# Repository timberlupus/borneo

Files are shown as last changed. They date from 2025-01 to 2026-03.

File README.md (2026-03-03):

# BorneoIoT: Professional Aquarium Lighting Platform








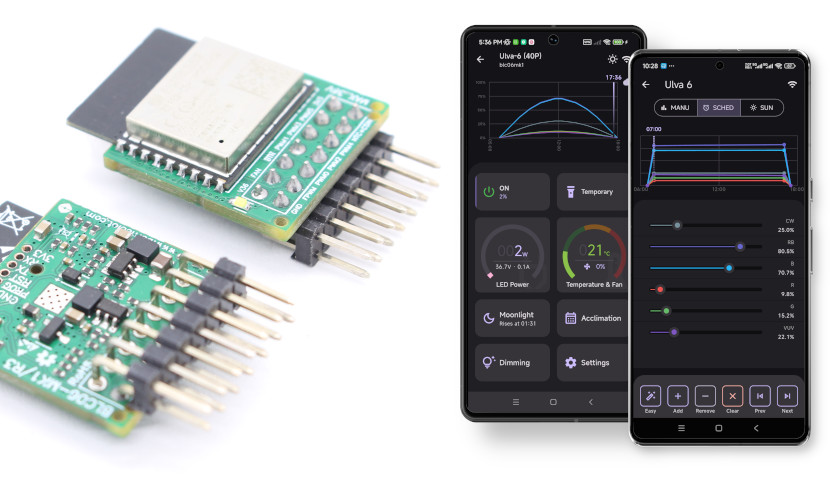
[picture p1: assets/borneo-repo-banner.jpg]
BorneoIoT Banner


<p align="center">
        <a href="https://www.borneoiot.com"><b>Website</b></a> •
        <a href="https://docs.borneoiot.com"><b>Documentation</b></a> •
        <a href="https://github.com/borneo-iot/borneo/discussions"><b>Forum</b></a> •
        <a href="https://discord.gg/EFJTm7PpEs"><b>Discord</b></a> •
</p>

<p align="center">
    <a href="https://www.crowdsupply.com/borneo-iot/buce-aquarium-led-controller" target="_blank" rel="noopener">
        
    </a>
    <a href="https://flasher.borneoiot.com">
        
    </a>

</p>

> **Production-grade open-source stack for aquarium LED dimmers.**
> Hardware designs, embedded firmware, and mobile controls. Ready for weekend builds or product integration.

This project delivers a full-stack solution for smart aquarium LED:

1.  **Hardware**: Certified open-source PCB designs targeting the ESP32 family, featuring 6-channel PWM dimming and modular architecture.
2.  **Firmware**: A robust ESP-IDF based firmware implementing CoAP/CBOR protocols, sunrise/sunset simulation, and cooling control.
3.  **Mobile App**: A cross-platform Flutter application for intuitive real-time control, scheduling, and device management.

## Quick Start

**New users:** Follow the **[step-by-step guide](https://docs.borneoiot.com/getting-started/quick-start.html)** to flash firmware and connect your first device.

**No toolchain required**, flash directly from Chrome/Edge Browser:

1. Connect ESP32/ESP32-C3/ESP32-C5 via USB
2. Visit **[flasher.borneoiot.com](https://flasher.borneoiot.com)**
3. Download the app and power on

[Full Getting Started Guide](https://docs.borneoiot.com/getting-started)

## Features

### Hardware

- **6 or 10 PWM channels**, 12-bit resolution (4096 steps), up to 19kHz
- **Flicker-free**, suitable for aquarium photography
- **22×30mm core module**, fits slim LED fixtures
- ESP32-C3/C5 native, WiFi + Bluetooth LE

[Schematics & BoM](hw/)

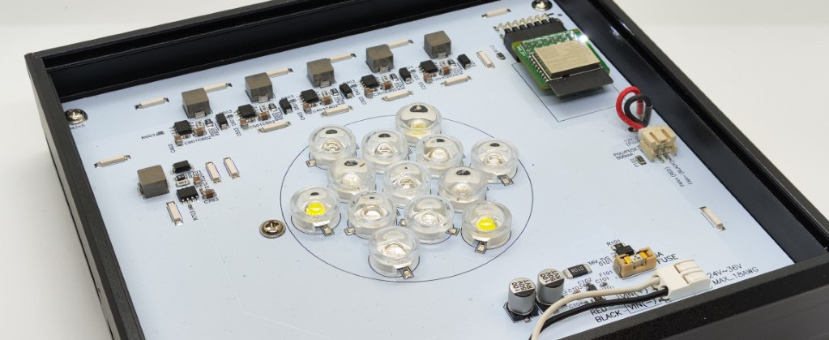
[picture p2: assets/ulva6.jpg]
Ulva-6


### Firmware

- **Sunrise/sunset curves** with millisecond-smooth transitions
- **SNTP time sync**: automatic, no manual adjustment
- **Active cooling control**: temperature-based fan/PWM throttling
- **OTA updates**: over-the-air firmware upgrades
- **CoAP + CBOR protocol**: efficient, low-latency device communication

[Source code](fw/) • [Protocol docs](https://docs.borneoiot.com/protocol)

### Mobile App

- **Cross-platform**: iOS, Android, Windows, built with Flutter
- **Real-time control**: dimming, scheduling, scene presets
- **Multi-device**: group control, cloud-free local network
- **Developer API**: Python client for automation

[App source](client/) • [Python SDK](borneopy/)

## Repository Guide

| Directory | Contents | Entry Point |
|---|---|---|
| [`hw/`](hw/) | PCB designs (Horizon EDA), Gerbers, 3D models | [`hw/README.md`](hw/) |
| [`fw/`](fw/) | ESP-IDF firmware, CoAP protocol | [`fw/README.md`](fw/) |
| [`client/`](client/) | Flutter mobile app | [`client/README.md`](client/) |
| [`borneopy/`](borneopy/) | Python client library | [`borneopy/README.md`](borneopy/) |

## Getting Started

- **New Users**: Check out our [**Quick Start Guide**](https://docs.borneoiot.com/getting-started/quick-start.html).
- If you are a new user looking to quickly experience our firmware, you can directly use our web firmware flasher to flash the latest version of the firmware to your ESP32 series development board: https://flasher.borneoiot.com/
- **Hardware**: Find schematics and BoM files in the [`hw/`](hw/) directory.
- **Firmware**: Compilation instructions are available in the [`fw/`](fw/) folder.

## Project Status

| Component | Status | Details |
| :--- | :--- | :--- |
| **Hardware** | Stable | Production-ready, OSHWA certified. |
| **Firmware** | Beta | Full-featured and stable on my personal tanks for years. |
| **Mobile App** | Beta | Core functionality working. |

## Roadmap

Check our [milestones](https://github.com/borneo-iot/borneo/milestones) for the latest development updates and upcoming features.

## Community & Support

- **Website**: [www.borneoiot.com](https://www.borneoiot.com)
- **Documentation**: [docs.borneoiot.com](https://docs.borneoiot.com)
- **Discussions**: [Join the Conversation](https://github.com/borneo-iot/borneo/discussions)
- **Discord**: [Connect with Developers](https://discord.gg/EFJTm7PpEs)
- **Email**: [info@binarystarstech.com](mailto:info@binarystarstech.com)

## Licenses

- **Software/Firmware**: Dual-licensed under [**GPL-3.0+**](LICENSE) and Enterprise licenses.
- **Hardware**: Licensed under [**CERN-OHL-S-2.0**](LICENSE-HARDWARE).

---

The hardware, firmware, and App for this project were all created by: Wei Li（李维）.

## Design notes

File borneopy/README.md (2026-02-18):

# borneo.py

A open-source Python client library for devices under the Borneo-IoT Project.

## Features

- Basic device control (power on/off, reboot, factory reset, etc.)
- Device information queries
- Timezone settings
- Firmware upgrade checking
- CoAP OTA firmware updates

## Installation

```bash
pip install -r requirements.txt
```

## Usage Examples

### Basic Device Control

```python
import asyncio
from borneo.lyfi import LyfiCoapClient

async def main():
    async with LyfiCoapClient("coap://192.168.1.100") as device:
        # Get device information
        info = await device.get_info()
        print(f"Device info: {info}")
        
        # Control device power
        await device.set_on_off(True)
        status = await device.get_on_off()
        print(f"Device status: {status}")

if __name__ == "__main__":
    asyncio.run(main())
```

### CoAP OTA Firmware Update

```python
import asyncio
from borneo.lyfi import LyfiCoapClient

async def update_firmware():
    device_url = "coap://192.168.1.100"
    firmware_path = "firmware.bin"
    
    def progress_callback(current, total):
        percent = int((current / total) * 100)
        print(f"Upload progress: {percent}%")
    
    def status_callback(message):
        print(f"Status: {message}")
    
    async with LyfiCoapClient(device_url) as device:
        # Check OTA status
        status = await device.check_ota_status()
        if status['success']:
            print(f"Current partition: {status['current_partition']}")
        
        # Execute OTA update
        result = await device.perform_ota_update(
            firmware_path,
            progress_callback=progress_callback,
            status_callback=status_callback
        )
        
        if result['success']:
            print("Firmware update successful!")
        else:
            print(f"Update failed: {result['error']}")

if __name__ == "__main__":
    asyncio.run(update_firmware())
```

## Command Line Tools

### `bocli` — command-line tool 🔧

`bocli` is the console script provided by this package (see `pyproject.toml`).
Install the package to get the `bocli` command (`pip install -e .`) or run via `uv run bocli`.

Usage:

```text
bocli [global options] <command> [command options]
```

Global options
- `-h, --host`  Device base URL for CoAP commands (e.g. `coap://192.168.1.10`)
- `-v, --verbose`  Increase verbosity (repeatable)
- `-c, --compatible`  Compatibility string (default: `bst,borneo-lyfi`)
- `--version`  Print version and exit

Available commands
- `lota` — perform local OTA over CoAP
  - usage: `bocli -h coap://192.168.1.100 lota firmware.bin [--block-size 512] [--status-only]`
  - note: `fw_path` is required; `--status-only` will only query OTA status and exit
- `mdns` — discover devices via mDNS (e.g. `bocli mdns -t 5` or `bocli mdns --find`)
- `get` — call `get_<what>` on `LyfiCoapClient` and print JSON
  - usage: `bocli -h coap://192.168.1.100 get color`
  - list targets: `bocli -h coap://192.168.1.100 get --list`
- `capabilities` — list available `get_...` methods (supports `--json`)
- `on` / `off` — turn device on / off (e.g. `bocli -h coap://192.168.1.100 on`)
- `factory-reset` — perform factory reset (use `-y` to bypass confirmation)

Examples
```bash
# discover devices with mDNS for 3 seconds
bocli mdns -t 3

# list `get_...` targets supported by the device
bocli -h coap://192.168.1.100 get --list

# get a resource (prints JSON)
bocli -h coap://192.168.1.100 get color

# turn device on
bocli -h coap://192.168.1.100 on

# perform OTA (upload firmware)
bocli -h coap://192.168.1.100 lota firmware.bin
# check OTA status only (fw_path is still required by the CLI)
bocli -h coap://192.168.1.100 lota firmware.bin --status-only
```

See `borneo/cli.py` for full command descriptions and options.

## API Documentation

### CoAP OTA Methods

#### `check_ota_status()`
Check device OTA status.

**Returns:**
```python
{
    'success': bool,
    'current_partition': str,      # Current running partition
    'update_status': str,          # Update status
    'bytes_received': int          # Bytes received
}
```

#### `upload_firmware(firmware_path, progress_callback=None)`
Upload firmware file to device.

**Parameters:**
- `firmware_path`: Path to firmware file
- `progress_callback`: Optional progress callback function `callback(current, total)`

**Returns:**
```python
{
    'success': bool,
    'message': str,
    'next_boot': str,              # Next boot partition
    'checksum': str,               # File checksum
    'size': int                    # File size
}
```

#### `perform_ota_update(firmware_path, progress_callback=None, status_callback=None)`
Execute complete OTA update process.

**Parameters:**
- `firmware_path`: Path to firmware file
- `progress_callback`: Optional progress callback function `callback(current, total)`
- `status_callback`: Optional status callback function `callback(message)`

**Returns:**
```python
{
    'success': bool,
    'message': str,
    'details': dict                # Detailed result information
}
```

## Dependencies

- `aiocoap>=0.4.12` - CoAP protocol support
- `cbor2>=5.6.5` - CBOR data format support
- `aiofiles` - Async file operations

## Packaging & development

This project uses a modern PEP 621 `pyproject.toml` (setuptools backend). Below are common development and packaging commands.

- Build distributions:
  - `python -m build` (uses build backend from `pyproject.toml`)
  - `uv build` (if you use Astral's `uv` tool)

- Create and activate a local virtual environment (Windows):
  - `python -m venv .venv`
  - `.venv/Scripts/activate`

- Install dependencies for development:
  - `pip install -e .`
  - or `uv pip sync` / `uv venv` when using `uv`

- Run an example:
  - `python examples/hello_lyfi.py`

- Publish to PyPI:
  - `uv publish`
  - or `python -m twine upload dist/*`

Notes:
- **License:** `GPL-3.0-or-later` — please add or verify a `LICENSE` file in the repository.
- The project was migrated from `setup.py` to `pyproject.toml`; builds produce both `sdist` and `wheel` artifacts.

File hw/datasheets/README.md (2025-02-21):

# Datasheets

This folder contains the schematics and datasheets for the hardware developed in this project.

| Module / Name | Datasheet | Other Language Version |
|:--- | :--- | :--- |
| Buce (BLC06MK1) Module Datasheet | [`blc06mk1.pdf`](blc06mk1.pdf) | - |
| Buce (BLC06MK1) Module Schematic | [`blc06mk1r4_sch.pdf`](blc06mk1r4_sch.pdf) | - |

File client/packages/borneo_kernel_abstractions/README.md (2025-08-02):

# Borneo Kernel Abstractions

This package provides core abstractions and interfaces for the Borneo project kernel.

## Features

- Device and driver interfaces
- Device event bus
- Command queue
- Error types for device operations
- mDNS discovery abstractions
- Bound device and driver data models

## Usage

Add to your `pubspec.yaml` dependencies:

```yaml
dependencies:
  borneo_kernel_abstractions:
    path: packages/borneo_kernel_abstractions
```

Import what you need:

```dart
import 'package:borneo_kernel_abstractions/kernel.dart';
```

Or import specific interfaces or models:

```dart
import 'package:borneo_kernel_abstractions/ikernel.dart';
```

## License

See [LICENSE](LICENSE).

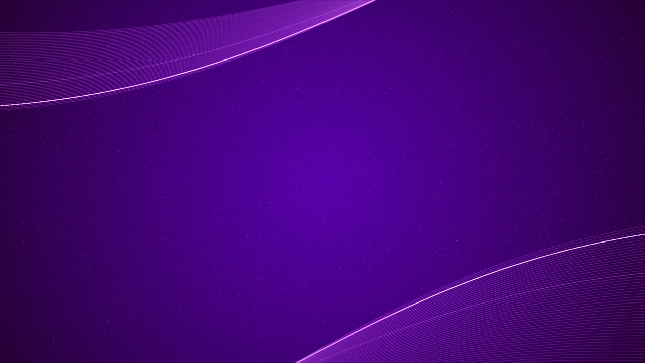
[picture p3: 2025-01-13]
client/assets/images/scenes/scene-default-noimage.jpg

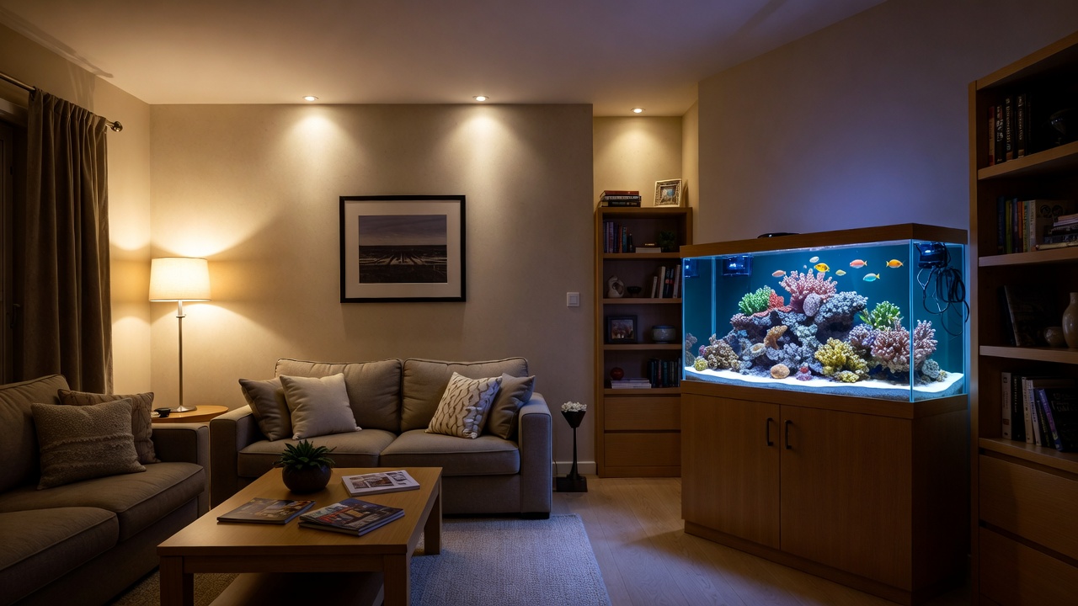
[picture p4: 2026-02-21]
client/assets/images/scenes/scene-default-home.jpg

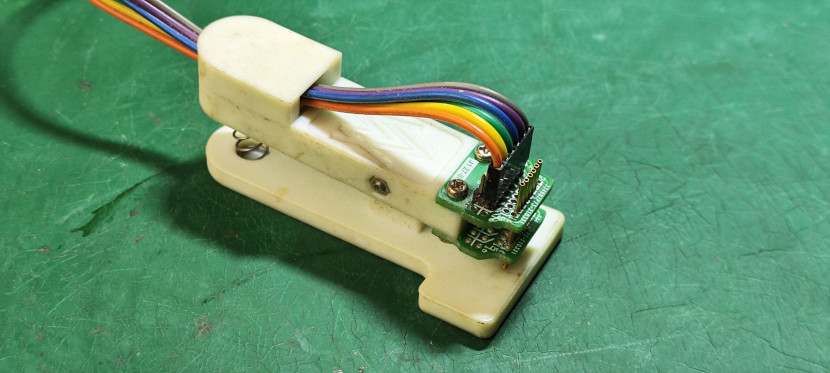
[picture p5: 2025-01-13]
assets/programming-clamp.jpg

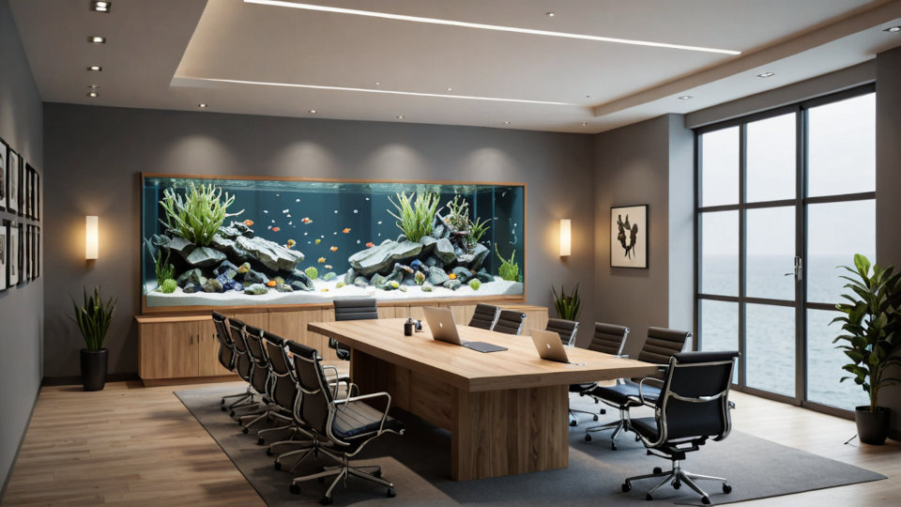
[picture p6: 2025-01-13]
client/assets/images/scenes/scene-default-office.jpg

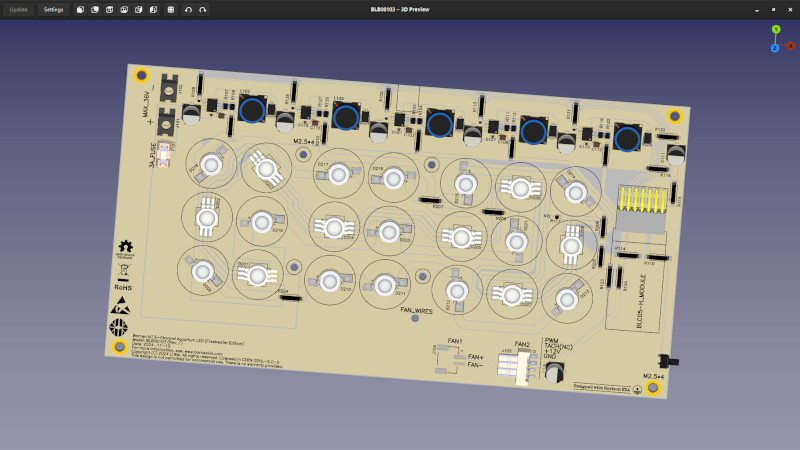
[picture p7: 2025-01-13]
assets/blb08103.jpg

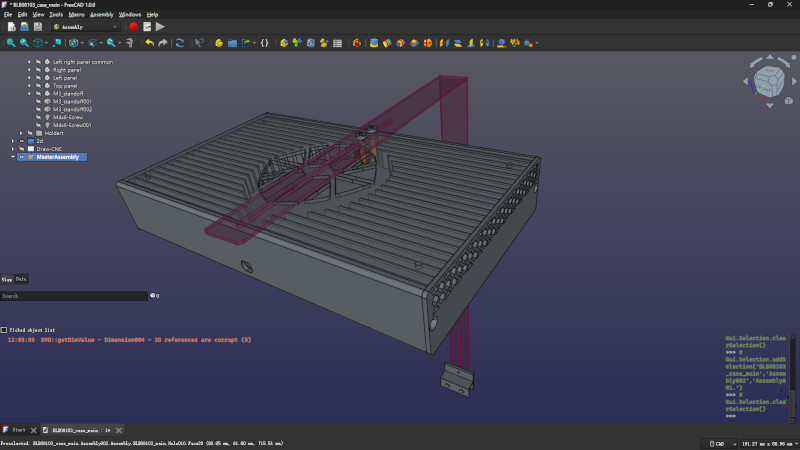
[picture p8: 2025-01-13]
assets/blb08103-case.jpg

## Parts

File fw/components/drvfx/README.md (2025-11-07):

# DRVFX: ESP-IDF modular device driver framework

## Overview

Borrowed from Zephyr RTOS: an ESP-IDF modular device driver framework.

## Purpose

This component provides a small, modular driver/kernel abstraction for device drivers used by the project. It centralizes device registration, initialization, and driver interfaces so platform drivers can be developed and reused consistently.

## Layout

- `include/drvfx/`: public headers for the framework and drivers.
- `drivers/`: example and platform drivers (RTC driver located under `drivers/rtc`).
- `kernel/`: core implementation (kernel/device/init source files).
- `LICENSE.txt`: licensing for this component.

Key headers are under `include/drvfx/kernel` and `include/drvfx/drivers` and provide the API surface for integrating drivers.

## Usage

Add the component to your ESP-IDF project as usual (CMake/IDF component). Include the public headers from `include/drvfx` and use the provided kernel/device APIs to register and manage drivers. Consult the `drivers/` directory for usage examples.

### Subsystem init

Use `DRVFX_SUBSYS_INIT` to register a subsystem initialization function that runs at the POST_KERNEL stage. The init function signature is:

```c
int init_fn(const struct drvfx_device *dev);
```

For subsystem entries `dev` will be NULL. Return 0 on success; non-zero indicates failure. Priority controls ordering (use constants like `DRVFX_INIT_POST_KERNEL_DEFAULT_PRIORITY`).

Example:

```c
/* module.c */
#include <drvfx/kernel/init.h>

static int my_subsys_init(const struct drvfx_device *dev)
{
    (void)dev; /* subsys entries have no device */
    /* perform subsystem setup here */
    return 0;
}

/* Register the subsystem init at post-kernel default priority */
DRVFX_SUBSYS_INIT(my_subsys_init, DRVFX_INIT_POST_KERNEL_DEFAULT_PRIORITY);
```

Notes:

- Use `DRVFX_SYS_INIT` / `DRVFX_SYS_INIT_NAMED` when you need a system init entry associated with the init function name.
- Subsystem inits run automatically during kernel initialization (e.g., when `k_init()` is invoked). After init, use `k_device_get_binding()` and `k_device_is_ready()` to access devices.

## Driver development example — foo

This example shows a minimal driver API for a device type `foo` whose API exposes a single function `foo_read(dev, buf, size)`.

Header (`foo.h`):

```c
#pragma once

#include <errno.h>
#include <drvfx/drvfx.h>

#ifdef __cplusplus
extern "C" {
#endif

struct foo_api {
    int (*read)(const struct drvfx_device *dev, void *buf, size_t size);
};

/* User-land API: forwards the call to the driver implementation. */
static inline int foo_read(const struct drvfx_device *dev, void *buf, size_t size)
{
    const struct foo_api *api = (const struct foo_api *)dev->api;
    return api->read(dev, buf, size);
}

#ifdef __cplusplus
}
#endif
```

Driver implementation (`foo.c`):

```c
#include <drvfx/drvfx.h>

static int foo_read_impl(const struct drvfx_device *dev, void *buf, size_t size)
{
    (void)dev;
    /* perform read into buf up to size bytes */
    return 0; /* return number of bytes read or negative on error */
}

static int foo_init(const struct drvfx_device *dev)
{
    (void)dev;
    /* hardware init for foo */
    return 0;
}

static const struct foo_api foo_api_impl = {
    .read = foo_read_impl,
};

/* Define a static device and attach the API pointer */
DRVFX_DEVICE_DEFINE(
    "foo0",
    foo_init,
    NULL,
    NULL, DRVFX_INIT_POST_KERNEL_DEFAULT_PRIORITY,
    &foo_api_impl
);
```

Runtime usage:

```c
#include <drvfx/drvfx.h>
#include "your_drivers_dir/foo.h"

void drvfx_app_main(void)
{
    const struct drvfx_device *dev = k_device_get_binding("foo0");
    if (dev && k_device_is_ready(dev)) {
        const struct foo_api *api = (const struct foo_api *)dev->api;
        if (api && api->read) {
            char buf[32];
            int rc = api->read(dev, buf, sizeof(buf));
            // ...
        }
    }
}
```

Notes:

- Place the API definition in a public header, like under `include/your_porj/drivers/` so consumers can include it.
- Provide driver-specific `init` that sets up hardware and returns `0` on success.
- Attach the API pointer as the last argument to `DRVFX_DEVICE_DEFINE` so callers can cast `dev->api` to the driver API.

## Contributing / Contact

Follow the repository contribution guidelines. Open an issue or pull request in the main repository for feedback or improvements.

## License

This component is licensed in Apache 2.0 License.
See `LICENSE.txt` in this component for licensing details.

Copyright (C) 2024-TODAY Yunnan BinaryStars Technologies, Co., Ltd. All rights reserved.

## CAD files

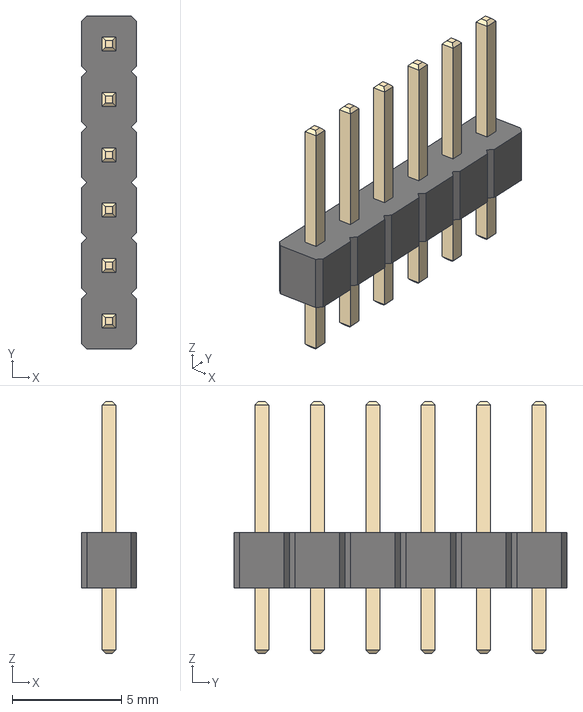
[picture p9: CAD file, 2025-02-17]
hw/bdb6mk1/pool/3d_models/cache/6d752bc3-29b3-45df-8cf2-1e3aacefbcc6/3d_models/connector/header/2.54mm/PinHeader_1x06_P2.54mm_Vertical.step
2.54 x 15.2 x 11.5 mm

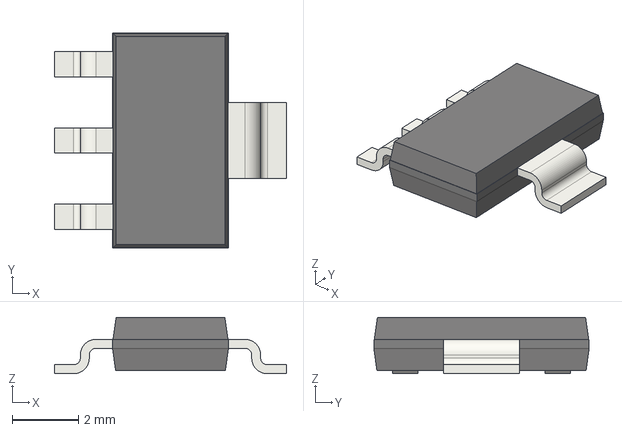
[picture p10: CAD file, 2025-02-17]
hw/bdb6mk1/pool/3d_models/cache/6d752bc3-29b3-45df-8cf2-1e3aacefbcc6/3d_models/ic/so/SOT-223.step
7.00 x 6.50 x 1.70 mm

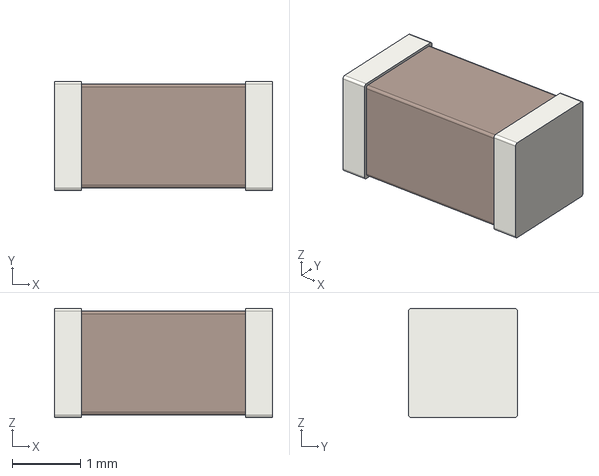
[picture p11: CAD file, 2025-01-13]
hw/bdb6mk1/pool/3d_models/cache/6d752bc3-29b3-45df-8cf2-1e3aacefbcc6/3d_models/passive/capacitor/C_1206_3216Metric.step
3.20 x 1.60 x 1.60 mm

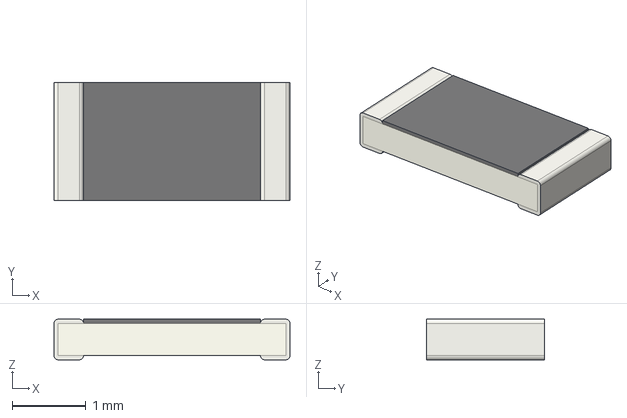
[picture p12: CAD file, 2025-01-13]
hw/bdb6mk1/pool/3d_models/cache/6d752bc3-29b3-45df-8cf2-1e3aacefbcc6/3d_models/passive/resistor/R_1206_3216Metric.step
3.20 x 1.60 x 0.55 mm

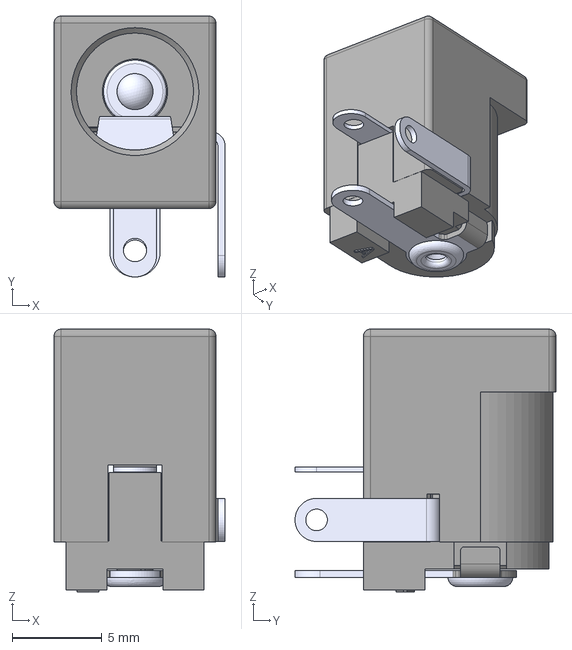
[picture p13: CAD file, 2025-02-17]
hw/bdb6mk1/pool/3d_models/cache/8eeaf956-e4a0-4db5-95bb-b90e600e8069/3d_models/connector/barrel-jack/DC-001-A-2.1mm-R.STEP
9.50 x 14.5 x 14.6 mm

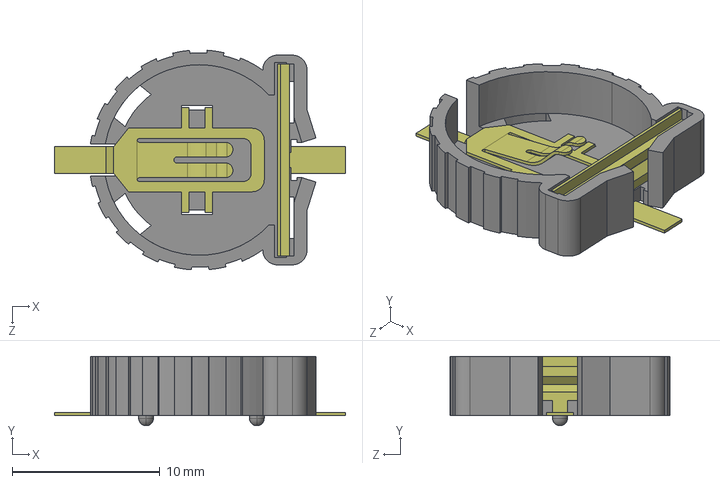
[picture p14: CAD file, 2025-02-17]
hw/bdb6mk1/pool/3d_models/cache/8eeaf956-e4a0-4db5-95bb-b90e600e8069/3d_models/connector/battery-holder/CR1220-2.stp
19.7 x 4.70 x 14.9 mm

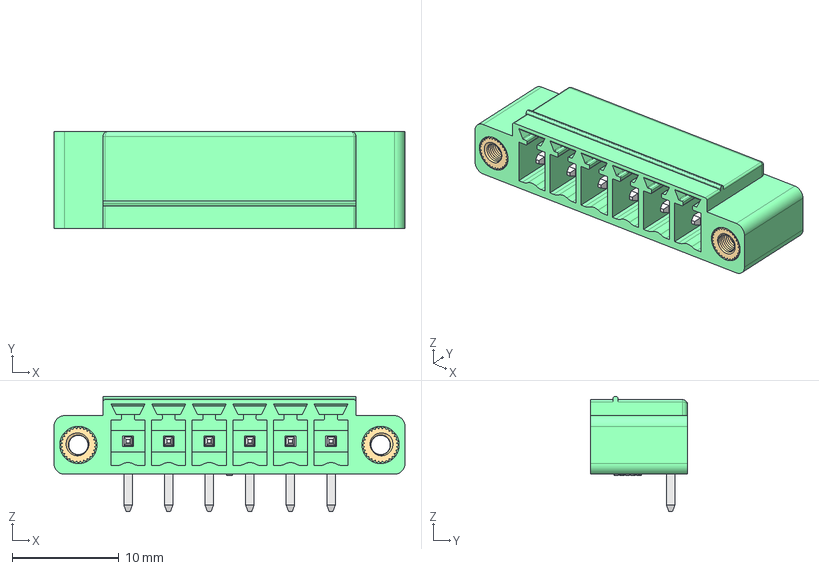
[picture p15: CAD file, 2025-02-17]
hw/bdb6mk1/pool/3d_models/cache/8eeaf956-e4a0-4db5-95bb-b90e600e8069/3d_models/connector/terminal-block/kangnex/WJ15EDGRM-3.81-06P.step
32.9 x 9.15 x 10.8 mm

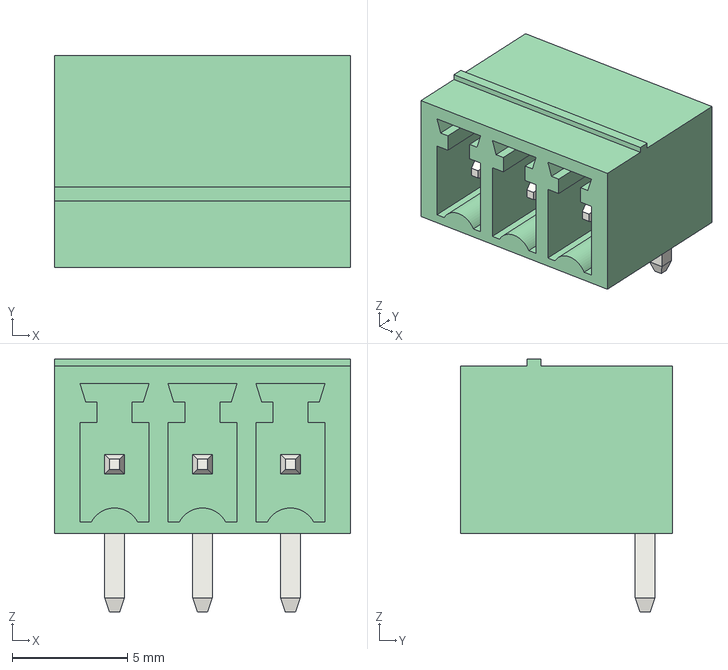
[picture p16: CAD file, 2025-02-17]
hw/bdb6mk1/pool/3d_models/cache/8eeaf956-e4a0-4db5-95bb-b90e600e8069/3d_models/connector/terminal-block/phoenix-contact-mc/PhoenixContact_MC_1,5_3-G-3.81_1x03_P3.81mm_Horizontal.step
12.8 x 9.20 x 10.9 mm

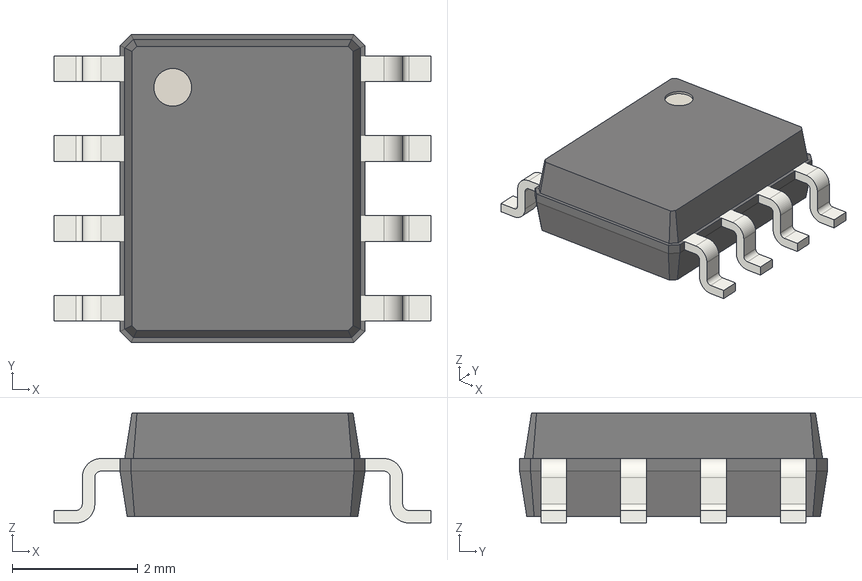
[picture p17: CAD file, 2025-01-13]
hw/bdb6mk1/pool/3d_models/cache/8eeaf956-e4a0-4db5-95bb-b90e600e8069/3d_models/ic/so/SOIC-8_3.9x4.9mm_P1.27mm.step
6.00 x 4.90 x 1.75 mm

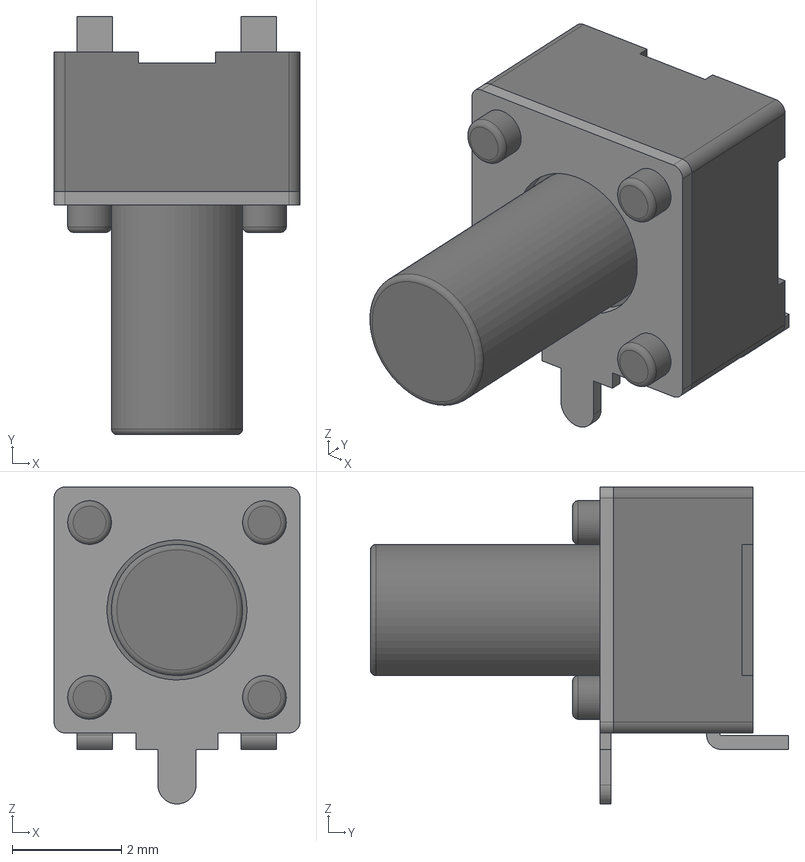
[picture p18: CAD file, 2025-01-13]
hw/bdb6mk1/pool/3d_models/cache/8eeaf956-e4a0-4db5-95bb-b90e600e8069/3d_models/mechanical/switch/krhro/K2-1109SE-I4SW-04.step
4.50 x 7.65 x 5.80 mm
Main
FrontPlate
Pin1
Pin2

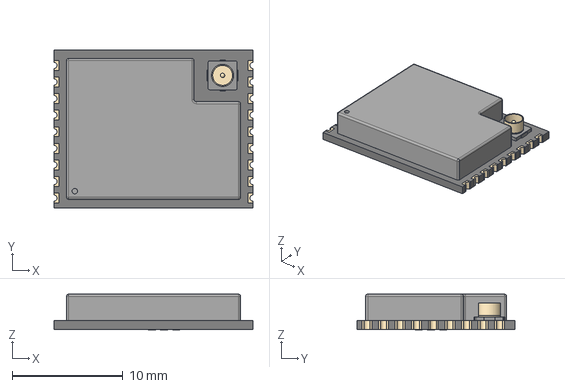
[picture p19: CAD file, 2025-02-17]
hw/bdb6mk1/pool/3d_models/cache/8eeaf956-e4a0-4db5-95bb-b90e600e8069/3d_models/module/rf/espressif/ESP32-C3-WROOM-02U.step
18.0 x 14.3 x 3.24 mm

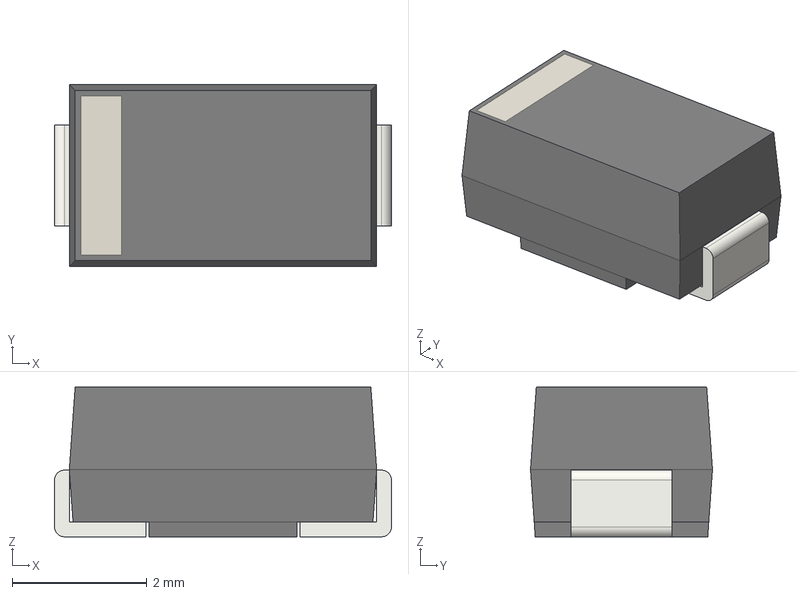
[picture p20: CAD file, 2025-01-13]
hw/blb0657f/pool/3d_models/cache/6d752bc3-29b3-45df-8cf2-1e3aacefbcc6/3d_models/diode/D_SMA.step
5.00 x 2.70 x 2.22 mm

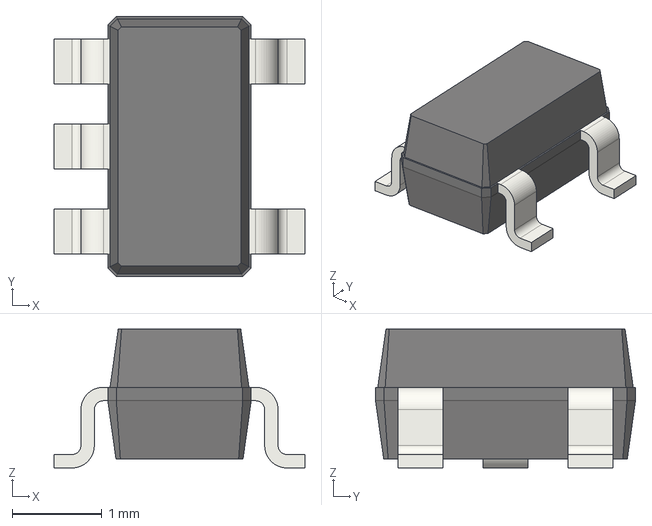
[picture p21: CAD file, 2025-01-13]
hw/blb0657f/pool/3d_models/cache/6d752bc3-29b3-45df-8cf2-1e3aacefbcc6/3d_models/ic/so/SOT-23-5.step
2.80 x 2.90 x 1.55 mm

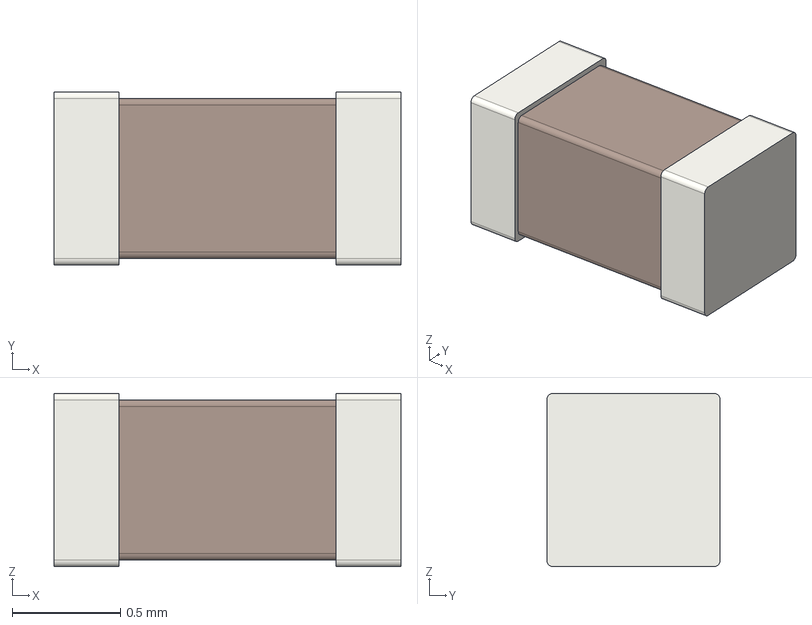
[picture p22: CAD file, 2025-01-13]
hw/blb0657f/pool/3d_models/cache/6d752bc3-29b3-45df-8cf2-1e3aacefbcc6/3d_models/passive/capacitor/C_0603_1608Metric.step
1.60 x 0.8 x 0.8 mm

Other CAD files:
hw/blb0657f/pool/3d_models/cache/6d752bc3-29b3-45df-8cf2-1e3aacefbcc6/3d_models/passive/resistor/R_0805_2012Metric.step
hw/blb0657f/pool/3d_models/cache/8eeaf956-e4a0-4db5-95bb-b90e600e8069/3d_models/connector/b2w/2.54mm/2510_4p_smd_horizontal.step
hw/blb0657f/pool/3d_models/cache/8eeaf956-e4a0-4db5-95bb-b90e600e8069/3d_models/connector/b2w/jst/2.00mm/S2B-PH-SM4-TB_LF__SN_.step
hw/blb0657f/pool/3d_models/cache/8eeaf956-e4a0-4db5-95bb-b90e600e8069/3d_models/connector/header/2.54mm/PinHeader_2x07_P2.54mm_Horizontal.step
hw/bdb6mk1/pool/3d_models/cache/6d752bc3-29b3-45df-8cf2-1e3aacefbcc6/3d_models/ic/so/SOT-23.step
hw/bdb6mk1/pool/3d_models/cache/8eeaf956-e4a0-4db5-95bb-b90e600e8069/3d_models/module/rf/espressif/ESP32-C3-WROOM-02.STEP
hw/blb0657f/pool/3d_models/cache/8eeaf956-e4a0-4db5-95bb-b90e600e8069/3d_models/connector/b2w/jst/2.00mm/S4B-PH-SM4-TB_LF__SN_.step
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

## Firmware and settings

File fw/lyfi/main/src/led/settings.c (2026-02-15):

#include <string.h>
#include <time.h>
#include <errno.h>
#include <math.h>
#include <stdio.h>
#include <ctype.h>

#include <esp_system.h>
#include <esp_event.h>
#include <esp_timer.h>
#include <freertos/FreeRTOS.h>
#include <freertos/task.h>
#include <freertos/semphr.h>
#include <driver/ledc.h>
#include <esp_err.h>
#include <esp_log.h>
#include <nvs_flash.h>
#include <esp_rom_md5.h>

#include <borneo/common.h>
#include <borneo/system.h>
#include <borneo/power.h>
#include <borneo/nvs.h>

#include "../lyfi-events.h"
#include "led.h"

#define LED_NVS_NS "led"
#define LED_NVS_KEY_RUNNING_MODE "mode"
#define LED_NVS_KEY_MANUAL_COLOR "mcolor"
#define LED_NVS_KEY_SUN_COLOR "suncolor"
#define LED_NVS_KEY_MOON_COLOR "mooncolor"
#define LED_NVS_KEY_SCHEDULER "sch"
#define LED_NVS_KEY_TEMPORARY_DURATION "tmpdur"
#define LED_NVS_KEY_CORRECTION_METHOD "corrmtd"
#define LED_NVS_KEY_PWM_FREQ "pwmfreq"
#define LED_NVS_KEY_CHANNEL_COUNT "chcount"
#define LED_NVS_KEY_LOC "loc"
#define LED_NVS_KEY_TZ_ENABLED "tz_en"
#define LED_NVS_KEY_TZ_OFFSET "tz_off"
#define LED_NVS_KEY_ACCLIMATION_ENABLED "acc.en"
#define LED_NVS_KEY_ACCLIMATION_START "acc.start"
#define LED_NVS_KEY_ACCLIMATION_DURATION "acc.days"
#define LED_NVS_KEY_ACCLIMATION_START_PERCENT "acc.pc"
#define LED_NVS_KEY_CLOUD_ENABLED "cloud.en"
#define LED_NVS_KEY_MOON_ENABLED "moon.en"

#define TAG "led.settings"

static const struct led_user_settings LED_DEFAULT_SETTINGS = {
    .mode = LED_MODE_MANUAL,
    .temporary_duration = 20,
    .manual_color = {
// From kconfig
#if CONFIG_LYFI_LED_CH0_ENABLED
        205,
#endif
#if CONFIG_LYFI_LED_CH1_ENABLED
        205,
#endif
#if CONFIG_LYFI_LED_CH2_ENABLED
        205,
#endif
#if CONFIG_LYFI_LED_CH3_ENABLED
        205,
#endif
#if CONFIG_LYFI_LED_CH4_ENABLED
        205,
#endif
#if CONFIG_LYFI_LED_CH5_ENABLED
        205,
#endif
#if CONFIG_LYFI_LED_CH6_ENABLED
        205,
#endif
#if CONFIG_LYFI_LED_CH7_ENABLED
        205,
#endif
#if CONFIG_LYFI_LED_CH8_ENABLED
        205,
#endif
#if CONFIG_LYFI_LED_CH9_ENABLED
        205,
#endif
    },

    .correction_method = LED_CORRECTION_CIE1931,

    .sun_color = { 0 },
    .moon_color = { 0 },
    .scheduler = { 0 },

    .location = { // Kunming, China
        .lat = 25.0430f,
        .lng = 102.7062f,
    },
    .tz_offset = 8 * 3600, // UTC+8

    .flags = 0ULL,

    .acclimation = {
        .start_utc = 0,
        .duration = 30,
        .start_percent = 30,
    },
};

struct led_channel_defaults {
    const char* name;
    const char* color;
    int16_t wavelength;
};

static const struct led_channel_defaults LED_DEFAULT_CHANNELS[CONFIG_LYFI_LED_CHANNEL_COUNT] = {
#if CONFIG_LYFI_LED_CH0_ENABLED
    [0] = {
            .name = CONFIG_LYFI_LED_CH0_NAME,
            .color = CONFIG_LYFI_LED_CH0_COLOR,
            .wavelength = CONFIG_LYFI_LED_CH0_WAVELENGTH,
        },
#endif
#if CONFIG_LYFI_LED_CH1_ENABLED
    [1] = {
            .name = CONFIG_LYFI_LED_CH1_NAME,
            .color = CONFIG_LYFI_LED_CH1_COLOR,
            .wavelength = CONFIG_LYFI_LED_CH1_WAVELENGTH,
        },
#endif
#if CONFIG_LYFI_LED_CH2_ENABLED
    [2] = { 
            .name = CONFIG_LYFI_LED_CH2_NAME,
            .color = CONFIG_LYFI_LED_CH2_COLOR,
            .wavelength = CONFIG_LYFI_LED_CH2_WAVELENGTH,
         },
#endif
#if CONFIG_LYFI_LED_CH3_ENABLED
    [3] = {
            .name = CONFIG_LYFI_LED_CH3_NAME,
            .color = CONFIG_LYFI_LED_CH3_COLOR,
            .wavelength = CONFIG_LYFI_LED_CH3_WAVELENGTH,
        },
#endif
#if CONFIG_LYFI_LED_CH4_ENABLED
    [4] = {
            .name = CONFIG_LYFI_LED_CH4_NAME,
            .color = CONFIG_LYFI_LED_CH4_COLOR,
            .wavelength = CONFIG_LYFI_LED_CH4_WAVELENGTH,
        },
#endif
#if CONFIG_LYFI_LED_CH5_ENABLED
    [5] = {
            .name = CONFIG_LYFI_LED_CH5_NAME,
            .color = CONFIG_LYFI_LED_CH5_COLOR,
            .wavelength = CONFIG_LYFI_LED_CH5_WAVELENGTH,
        },
#endif
#if CONFIG_LYFI_LED_CH6_ENABLED
    [6] = {
            .name = CONFIG_LYFI_LED_CH6_NAME,
            .color = CONFIG_LYFI_LED_CH6_COLOR,
            .wavelength = CONFIG_LYFI_LED_CH6_WAVELENGTH,
        },
#endif
#if CONFIG_LYFI_LED_CH7_ENABLED
    [7] = {
            .name = CONFIG_LYFI_LED_CH7_NAME,
            .color = CONFIG_LYFI_LED_CH7_COLOR,
            .wavelength = CONFIG_LYFI_LED_CH7_WAVELENGTH,
        },
#endif
#if CONFIG_LYFI_LED_CH8_ENABLED
    [8] = {
            .name = CONFIG_LYFI_LED_CH8_NAME,
            .color = CONFIG_LYFI_LED_CH8_COLOR,
            .wavelength = CONFIG_LYFI_LED_CH8_WAVELENGTH,
        },
#endif
#if CONFIG_LYFI_LED_CH9_ENABLED
    [9] = {
        .name = CONFIG_LYFI_LED_CH9_NAME,
        .color = CONFIG_LYFI_LED_CH9_COLOR,
        .wavelength = CONFIG_LYFI_LED_CH9_WAVELENGTH,
    },
#endif
};

static struct led_factory_settings s_factory_settings;
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

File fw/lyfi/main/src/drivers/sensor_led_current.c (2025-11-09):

#include <errno.h>
#include <nvs_flash.h>

#include "sdkconfig.h"

#include <freertos/FreeRTOS.h>
#include <freertos/event_groups.h>
#include <freertos/task.h>

#include <esp_timer.h>
#include <esp_attr.h>
#include <esp_event.h>
#include <esp_log.h>
#include <esp_sntp.h>
#include <esp_system.h>
#include <driver/gpio.h>
#include <esp_adc/adc_oneshot.h>

#include <drvfx/drvfx.h>

#include <borneo/algo/filters.h>
#include <borneo/common.h>
#include <borneo/system.h>
#include <borneo/devices/adc.h>
#include <borneo/devices/sensor.h>

#define TAG "sensor.led_current"

#define BO_ADC_WINDOW_SIZE 5

#if CONFIG_LYFI_MEAS_CURRENT_SUPPORT

#define LED_NVS_NS "led"
#define LED_NVS_KEY_MEAS_CURRENT_ENABLED "curr.en"

#ifndef CONFIG_LYFI_MEAS_CURRENT_OFFSET
#define CONFIG_LYFI_MEAS_CURRENT_OFFSET 0
#endif

struct sensor_current_data {
    const struct drvfx_device* adc_dev;
    int32_t current_ma;
    int32_t filtered_current;
};

struct power_meas_factory_settings {
    bool measurement_enabled;
};

/*
static struct power_meas_factory_settings s_factory_settings = {
    .measurement_enabled = true,
};
*/

/*
static int factory_settings_load(void)
{
    nvs_handle_t nvs_handle;
    BO_TRY(bo_nvs_factory_open(LED_NVS_NS, NVS_READWRITE, &nvs_handle));
    BO_NVS_AUTO_CLOSE(nvs_handle);

    bool changed = false;
    uint8_t enabled = 1;

    BO_TRY(bo_nvs_get_or_set_u8(nvs_handle, LED_NVS_KEY_MEAS_CURRENT_ENABLED, &enabled, 1, &changed));

    if (changed) {
        BO_TRY(nvs_commit(nvs_handle));
    }

    s_factory_settings.measurement_enabled = (enabled != 0);

    return 0;
}
*/

static int _fetch_sample(const struct drvfx_device* dev)
{
    if (dev == NULL) {
        return -ENODEV;
    }
    if (dev->data == NULL) {
        return -ENOSYS;
    }
    struct sensor_current_data* data = (struct sensor_current_data*)dev->data;

    int32_t adc_mv;
    BO_TRY(adc_read_mv(data->adc_dev, CONFIG_LYFI_MEAS_CURRENT_ADC_CHANNEL, &adc_mv));
    adc_mv -= CONFIG_LYFI_MEAS_CURRENT_OFFSET;
    if (adc_mv < 0) {
        adc_mv = 0;
    }
    int32_t raw_ma = (adc_mv * 1000 + (CONFIG_LYFI_MEAS_CURRENT_FACTOR / 2)) / CONFIG_LYFI_MEAS_CURRENT_FACTOR;
    data->current_ma = ema_filter(raw_ma, &data->filtered_current, 1, 10);
    return 0;
}

static int _get_value(const struct drvfx_device* dev, int32_t* value)
{
    if (dev == NULL) {
        return -ENODEV;
    }
    if (dev->data == NULL) {
        return -ENOSYS;
    }
    struct sensor_current_data* data = (struct sensor_current_data*)dev->data;
    *value = data->current_ma;
    return 0;
}

static int sensor_current_init(const struct drvfx_device* dev)
{
    if (dev == NULL) {
        return -ENODEV;
    }
    ESP_LOGI(TAG, "Initializing current sensor '%s'...", dev->name);

    if (dev->data == NULL) {
        return -ENOSYS;
    }
    struct sensor_current_data* data = (struct sensor_current_data*)dev->data;

    data->adc_dev = k_device_get_binding("adc");
    if (data->adc_dev == NULL) {
        ESP_LOGE(TAG, "Failed to get device 'adc'");
    }

    BO_TRY(_fetch_sample(dev));

    return 0;
}

const static struct sensor_api s_api = {
    .fetch_sample = &_fetch_sample,
    .get_value = &_get_value,
};

static struct sensor_current_data s_data = { 0 };

DRVFX_DEVICE_DEFINE("sensor.led_current", sensor_current_init, &s_data, NULL, DRVFX_INIT_POST_KERNEL_DEFAULT_PRIORITY,
                    &s_api);

#endif // CONFIG_LYFI_MEAS_CURRENT_SUPPORT

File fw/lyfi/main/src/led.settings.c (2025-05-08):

#include <string.h>
#include <time.h>
#include <errno.h>
#include <math.h>

#include <esp_system.h>
#include <esp_event.h>
#include <esp_timer.h>
#include <freertos/FreeRTOS.h>
#include <freertos/task.h>
#include <driver/ledc.h>
#include <esp_err.h>
#include <esp_log.h>
#include <nvs_flash.h>
#include <esp_rom_md5.h>

#include <borneo/common.h>
#include <borneo/system.h>
#include <borneo/power.h>
#include <borneo/nvs.h>

#include "lyfi-events.h"
#include "algo.h"
#include "led.h"

#define LED_NVS_NS "led"
#define LED_NVS_KEY_RUNNING_MODE "mode"
#define LED_NVS_KEY_MANUAL_COLOR "mcolor"
#define LED_NVS_KEY_SUN_COLOR "suncolor"
#define LED_NVS_KEY_SCHEDULER "sch"
#define LED_NVS_KEY_TEMPORARY_DURATION "tmpdur"
#define LED_NVS_KEY_CORRECTION_METHOD "corrmtd"
#define LED_NVS_KEY_PWM_FREQ "pwmfreq"
#define LED_NVS_KEY_LOC "loc"
#define LED_NVS_KEY_ACCLIMATION_ENABLED "acc.en"
#define LED_NVS_KEY_ACCLIMATION_START "acc.start"
#define LED_NVS_KEY_ACCLIMATION_DURATION "acc.days"
#define LED_NVS_KEY_ACCLIMATION_START_PERCENT "acc.pc"

static const struct led_user_settings LED_DEFAULT_SETTINGS = {
    .mode = LED_MODE_MANUAL,
    .temporary_duration = 20,
    .manual_color = {
// From kconfig
#if CONFIG_LYFI_LED_CH0_ENABLED
        5,
#endif
#if CONFIG_LYFI_LED_CH1_ENABLED
        5,
#endif
#if CONFIG_LYFI_LED_CH2_ENABLED
        5,
#endif
#if CONFIG_LYFI_LED_CH3_ENABLED
        5,
#endif
#if CONFIG_LYFI_LED_CH4_ENABLED
        5,
#endif
#if CONFIG_LYFI_LED_CH5_ENABLED
        5,
#endif
#if CONFIG_LYFI_LED_CH6_ENABLED
        5,
#endif
#if CONFIG_LYFI_LED_CH7_ENABLED
        5,
#endif
#if CONFIG_LYFI_LED_CH8_ENABLED
        5,
#endif
#if CONFIG_LYFI_LED_CH9_ENABLED
        5,
#endif
    },

    .correction_method = LED_CORRECTION_EXP,

    .sun_color = {0},
    .scheduler = { 0 },

    .location = {
        .lat = 25.0430f,
        .lng = 102.7062f,
    },

    .flags = 0ULL,

    .acclimation = {
        .enabled = false,
        .start_utc = 0,
        .duration = 30,
        .start_percent = 30,
    },
};

extern struct led_status _led;

int led_load_factory_settings(struct led_factory_settings* factory_settings)
{
    int rc;
    nvs_handle_t handle;
    rc = bo_nvs_factory_open(LED_NVS_NS, NVS_READWRITE, &handle);
    if (rc) {
        goto _EXIT_WITHOUT_CLOSE;
    }

    rc = nvs_get_u16(handle, LED_NVS_KEY_PWM_FREQ, &factory_settings->pwm_freq);
    if (rc == ESP_ERR_NVS_NOT_FOUND) {
        factory_settings->pwm_freq = CONFIG_LYFI_DEFAULT_PWM_FREQ;
        rc = 0;
    }
    if (rc) {
        goto _EXIT_CLOSE;
    }

_EXIT_CLOSE:
    bo_nvs_close(handle);
_EXIT_WITHOUT_CLOSE:
    return rc;
}

int led_load_user_settings()
{
    struct led_user_settings* settings = &_led.settings;
    int rc;
    size_t size;
    nvs_handle_t handle;
    rc = bo_nvs_user_open(LED_NVS_NS, NVS_READWRITE, &handle);
    if (rc) {
        goto _EXIT_WITHOUT_CLOSE;
    }

    {
        rc = nvs_get_u8(handle, LED_NVS_KEY_RUNNING_MODE, &settings->mode);
        if (rc == ESP_ERR_NVS_NOT_FOUND) {
            settings->mode = LED_DEFAULT_SETTINGS.mode;
            rc = 0;
        }
        if (rc) {
            goto _EXIT_CLOSE;
        }
    }

    {
        rc = nvs_get_u16(handle, LED_NVS_KEY_TEMPORARY_DURATION, &settings->temporary_duration);
        if (rc == ESP_ERR_NVS_NOT_FOUND) {
            settings->temporary_duration = LED_DEFAULT_SETTINGS.temporary_duration;
            rc = 0;
        }
        if (rc) {
            goto _EXIT_CLOSE;
        }
    }

    {
        size = sizeof(struct led_scheduler);
        rc = nvs_get_blob(handle, LED_NVS_KEY_SCHEDULER, &settings->scheduler, &size);
        if (rc == ESP_ERR_NVS_NOT_FOUND) {
            memcpy(&settings->scheduler, &LED_DEFAULT_SETTINGS.scheduler, sizeof(struct led_scheduler));
            rc = 0;
        }
        if (rc) {
            goto _EXIT_CLOSE;
        }
    }

    {
        size = sizeof(led_color_t);
        rc = nvs_get_blob(handle, LED_NVS_KEY_MANUAL_COLOR, &settings->manual_color, &size);
        if (rc == ESP_ERR_NVS_NOT_FOUND) {
            memcpy(&settings->manual_color, &LED_DEFAULT_SETTINGS.manual_color, sizeof(led_color_t));
            rc = 0;
        }
        if (rc) {
            goto _EXIT_CLOSE;
        }
    }

    {
        size = sizeof(led_color_t);
        rc = nvs_get_blob(handle, LED_NVS_KEY_SUN_COLOR, &settings->sun_color, &size);
        if (rc == ESP_ERR_NVS_NOT_FOUND) {
            memset(settings->sun_color, 0, sizeof(led_color_t));
            rc = 0;
        }
        if (rc) {
            goto _EXIT_CLOSE;
        }
    }

    {
        rc = nvs_get_u8(handle, LED_NVS_KEY_CORRECTION_METHOD, &settings->correction_method);
        if (rc == ESP_ERR_NVS_NOT_FOUND) {
            settings->correction_method = LED_DEFAULT_SETTINGS.correction_method;
            rc = 0;
        }
        if (rc) {
            goto _EXIT_CLOSE;
        }
    }
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

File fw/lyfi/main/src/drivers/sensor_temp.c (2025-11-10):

#include <string.h>
#include <sys/time.h>

#include <freertos/FreeRTOS.h>
#include <freertos/event_groups.h>
#include <freertos/task.h>

#include <esp_timer.h>
#include <esp_attr.h>
#include <esp_event.h>
#include <esp_log.h>
#include <esp_sntp.h>
#include <esp_system.h>
#include <driver/gpio.h>

#include <drvfx/drvfx.h>

#include <borneo/system.h>
#include <borneo/algo/filters.h>
#include <borneo/devices/adc.h>
#include <borneo/devices/sensor.h>

#if CONFIG_LYFI_NTC_SUPPORT

#define TAG "NTC"

struct ntc_data {
    const struct drvfx_device* adc_dev;
    int8_t temp_value;
    int32_t filtered_temp;
};

static int8_t ntc_table_lookup(int r);

#define NTC_SAMPLING_TIMES 8
#define NTC_TEMP_BUF_SIZE 16
#define NTC_ADC_MAX_VALUE 1023
#define ADC_WINDOW_SIZE 5

enum {
    NTC_SAMPLING_INTERVAL = 100,
    NTC_BAD_TEMPERATURE = -127,
};

// clang-format off

// 0~105 ℃

#if CONFIG_LYFI_NTC_PU_4K7
    // VRef=2.5V, 4.7kΩ Pull-up
const uint16_t NTC_MAPPING_TABLE[] = {
    2193, 2179, 2164, 2149, 2133, 2116, 2100, 2082, 2064, 2046,
    2028, 2009, 1989, 1969, 1949, 1928, 1907, 1885, 1863, 1841,
    1818, 1795, 1772, 1749, 1725, 1701, 1676, 1652, 1627, 1602,
    1578, 1552, 1527, 1502, 1477, 1451, 1426, 1401, 1376, 1350,
    1325, 1300, 1275, 1250, 1226, 1201, 1177, 1153, 1129, 1106,
    1082, 1059, 1036, 1014, 992, 970, 948, 927, 906, 885,
    865, 845, 825, 806, 787, 769, 750, 733, 715, 698,
    681, 665, 649, 633, 617, 602, 588, 573, 559, 545,
    532, 519, 506, 494, 481, 469, 458, 447, 436, 425,
    414, 404, 394, 384, 375, 366, 357, 348, 339, 331,
    323, 315, 308, 300, 293, 286,
};
#elif CONFIG_LYFI_NTC_PU_10K
    // VRef=3.3V, 10kΩ Pull-up
const uint16_t NTC_MAPPING_TABLE[] = {
    2549, 2518, 2486, 2453, 2420, 2386, 2352, 2318, 2283, 2247,
    2211, 2175, 2138, 2101, 2064, 2027, 1990, 1952, 1915, 1877,
    1840, 1802, 1765, 1727, 1690, 1654, 1617, 1581, 1545, 1509,
    1474, 1439, 1404, 1370, 1337, 1303, 1271, 1239, 1207, 1176,
    1146, 1116, 1087, 1058, 1030, 1002, 975, 949, 923, 898,
    873, 849, 826, 803, 781, 759, 738, 717, 697, 677,
    658, 640, 622, 604, 587, 571, 555, 539, 524, 509,
    495, 481, 467, 454, 442, 429, 417, 406, 394, 383,
    373, 362, 352, 343, 333, 324, 315, 307, 298, 290,
    282, 275, 267, 260, 253, 246, 240, 234, 227, 221,
    216, 210, 205, 199, 194, 189,
};
#else
#error "Unknown NTC pull-up resistor"
#endif

// clang-format on

enum {
    NTC_MAPPING_TABLE_SIZE = sizeof(NTC_MAPPING_TABLE) / sizeof(NTC_MAPPING_TABLE[0]),
};

static int8_t ntc_table_lookup(int value)
{

    int left = 0;
    int right = NTC_MAPPING_TABLE_SIZE - 1;
    int closest_index = NTC_BAD_TEMPERATURE;
    int min_diff = abs(NTC_MAPPING_TABLE[0] - value);

    while (left <= right) {
        int mid = left + (right - left) / 2;
        int difference = abs(NTC_MAPPING_TABLE[mid] - value);

        if (difference < min_diff) {
            min_diff = difference;
            closest_index = mid;
        }

        if (NTC_MAPPING_TABLE[mid] == value) {
            return mid;
        }
        else if (NTC_MAPPING_TABLE[mid] > value) {
            left = mid + 1;
        }
        else {
            right = mid - 1;
        }
    }

    return closest_index;
}

static int _fetch_sample(const struct drvfx_device* dev)
{
    if (dev == NULL) {
        return -ENODEV;
    }
    if (dev->data == NULL) {
        return -ENOSYS;
    }
    struct ntc_data* data = (struct ntc_data*)dev->data;

    int32_t adc_mv;
    BO_TRY(adc_read_mv(data->adc_dev, CONFIG_LYFI_NTC_ADC_CHANNEL, &adc_mv));
    if (adc_mv == 0 || adc_mv == 4095) {
        ESP_LOGE(TAG, "No NTC connected! sample_avg=%d", adc_mv);
        return -EIO;
    }

    int value = ntc_table_lookup(adc_mv);
    if (value == NTC_BAD_TEMPERATURE) {
        ESP_LOGE(TAG, "Bad temperature!");
        return -EIO;
    }
    data->temp_value = (int8_t)ema_filter((int32_t)value, &data->filtered_temp, 1, 10);
    return 0;
}

static int _get_value(const struct drvfx_device* dev, int32_t* value)
{
    if (dev == NULL) {
        return -ENODEV;
    }
    if (dev->data == NULL) {
        return -ENOSYS;
    }
    struct ntc_data* data = (struct ntc_data*)dev->data;
    *value = data->temp_value;
    return 0;
}

static int ntc_init(const struct drvfx_device* dev)
{
    if (dev == NULL) {
        return -ENODEV;
    }
    ESP_LOGI(TAG, "Initializing NTC '%s'...", dev->name);

    if (dev->data == NULL) {
        return -ENOSYS;
    }
    struct ntc_data* data = (struct ntc_data*)dev->data;

    data->adc_dev = k_device_get_binding("adc");
    if (data->adc_dev == NULL) {
        ESP_LOGE(TAG, "Failed to get device 'adc'");
    }

    BO_TRY(_fetch_sample(dev));

    return 0;
}

const static struct sensor_api s_api = {
    .fetch_sample = &_fetch_sample,
    .get_value = &_get_value,
};

static struct ntc_data s_data = { 0 };

DRVFX_DEVICE_DEFINE("sensor.temp", ntc_init, &s_data, NULL, DRVFX_INIT_POST_KERNEL_DEFAULT_PRIORITY, &s_api);

#endif // CONFIG_LYFI_NTC_SUPPORT

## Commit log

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2025-01-14 fix lyfi firmware sch_compute_current_color()
    [led.c]
2025-01-17 fix compilation issues for ESP32
    [fan.c]
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2025-01-22 fix blc05 placeholder
    [C_0402_1005Metric-HD.step]
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2025-02-17 add power measurement adc fix hpoint problems
    [adc.c, led.c, ntc.c]
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2025-02-21 fix pwm fan problem
    [fan.c]
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2025-03-03 oops, fix the fan pwm dac calc
    [fan.c]
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2025-03-09 oops, fix fan pwm algorithm
    [fan.c]
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2025-04-26 Add filter to ADC Improve dimming correction LUT Fix PID bug
    [led.c]
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2025-04-28 Fix wrong mode coap type
    [led.c]
2025-04-28 Fix powering off fading problem
    [led.c]
2025-04-30 fix nightlight starting up
    [led.c]
2025-05-01 Add coap ota initial implementation Fix geo-position
    [led.c]
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2025-05-08 fix powering on state
    [led.c]
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2025-05-15 fix event handler state switch
    [led.c]
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2025-05-20 * Refactor notification service and update related components to use IAppNotificationService * Fix temporary exit state problem
    [led.c, settings.c]
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2025-05-24 Update LED settings and improve brightness curve generation
    - Changed LED correction method from exponential to logarithmic in settings.c for better light output control.
    - Refactored CIE 1931 lookup table generation in cie1931.py to use a normalized function for improved accuracy.
    - Adjusted logarithmic lookup table generation to utilize an exponential form for better dimming perception.
    - Updated gamma correction default value from 2.2 to 2.6 for enhanced brightness adjustment.
    [settings.c]
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2025-05-25 Fix fan duty problem
    [fan.c]
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2025-05-26 Fix crash problem of powering off in temporary mode
    [led.c]
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2025-05-26 Add BO_COAP_TRY_DECODE macro for improved error handling in CoAP resource functions; update version to 0.3.8
    [fan.c]
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2025-05-31 feat: Add DeviceOfflineView to handle offline state for devices
    - Introduced a new DeviceOfflineView widget to display a message when the device is offline.
    - Updated lyfi_view.dart to use DeviceOfflineView based on device online status.
    - Refactored manual_editor_view.dart, sun_editor_view.dart, settings_screen.dart, and other files to replace lyfi_driver with lyfi_coap_driver.
    - Implemented BorneoCoapClient to manage CoAP requests and handle offline detection.
    - Enhanced BorneoLyfiCoapDriver to support new device capabilities and status checks.
    - Updated driver metadata to reflect changes in driver implementation.
    - Improved error handling and logging for device operations.
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2025-06-04 feat(coap): define known resource paths and add notification handling for resource changes
    fix(events): unify event base for LED and update event identifiers
    chore(version): bump version to 0.3.13
    [button.c, led.c]
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2025-06-06 fix(adc): update ADC window size to 9 for improved accuracy fix(power-meas): add delay in power read loop for stability fix(led): correct temporary off time calculation for LED state chore(version): 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
    [led.c]
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2025-06-07 Refactor device summary view models and driver data structure
    - Introduced `BaseBorneoSummaryDeviceViewModel` as a base class for summary view models.
    - Created `LyfiSummaryDeviceViewModel` to handle specific logic for Lyfi devices.
    - Updated `DeviceModuleMetadata` to use the new summary view model.
    - Replaced `DeviceSummaryViewModel` with `AbstractDeviceSummaryViewModel` for better abstraction.
    - Refactored `GroupedDevicesViewModel` to utilize the new summary view model structure.
    - Removed the old `DeviceSummaryViewModel` implementation.
    - Introduced `DriverData` class to encapsulate driver-related data and events.
    - Updated `Device` class to support typed driver data retrieval.
    - Refactor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
2025-06-07 fix: update synchronized package version and adjust line length in settings refactor: improve initialization logic in MainViewModel and add cancellation token support in device management
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2025-06-09 Refactor device list item layout for improved aesthetics and usability; replace ListTile with a custom Container for better styling
2025-06-09 Refactor device list tile layout for improved readability and maintainability; replace nested map with a for loop for clarity Update device icon in LyfiDeviceModuleMetadata for better visual represen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
2025-06-11 Refactor system and try headers; update device ID definition for EUI-64 format and implement error handling macros in new try.h file
2025-06-11 Refactor Lyfi device model to replace LedState and LedRunningMode with LyfiState and LyfiMode for improved clarity and consistency across the codebase.
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2025-06-15 Add comprehensive tests for WotThing and related components
    - Created `thing_test.dart` to test WotThing's properties, actions, events, and notification system.
    - Implemented tests for property management, action management, event management, and subscriber management.
    - Added edge case and error handling tests for WotThing.
    - Introduced `types_test.dart` to validate WotPrimitiveJsonType functionality.
    - Added `utils_test.dart` to test the timestamp utility function.
    - Created `value_test.dart` to ensure WotValue class operates correctly with various data types and scenarios.
    - Added basic structure for `wot_test.dart` to check exports.
    - Updated `pubspec.yaml` to include borneo_wot package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
2025-06-17 Refactor Lyfi Device Integration and Improve Resource Management
    - Removed obsolete lyfi_thing_example.dart file.
    - Replaced WotDevice + WotAdapter pattern with direct usage of WotProperty in wot.dart.
    - Introduced custom WotProperty classes (LyfiStateProperty, LyfiModeProperty, LyfiPowerProperty) for handling state, mode, and power events with proper event subscriptions.
    - Enhanced LyfiThing class to encapsulate all Lyfi-specific properties, actions, and events, including initialization and event handling.
    - Implemented dispose methods in WotThing and WotProperty to ensure proper resource cleanup and prevent memory leaks.
    - Added unit tests for dispose functionality in WotProperty and WotTh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
2025-06-18 Fix: Remove temporary fade period from LED off time calculation
    [led.c]
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2025-06-27 feat: Enhance DefaultKernel with improved error handling and resource management, and add unit tests for device operations
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2025-06-27 Refactor device management to use IDeviceManager interface
    - Replaced instances of DeviceManager with IDeviceManager across various files to improve abstraction and flexibility.
    - Updated method signatures and constructors to accept IDeviceManager where applicable.
    - Enhanced error handling in LyfiDeviceModuleMetadata by throwing InvalidOperationException instead of printing warnings.
    - Added cancellation token support in several view models and methods to allow for better control over asynchronous operations.
    - Adjusted imports to reflect the new interface structure for device and group management.
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2025-07-23 Add comprehensive tests for lw_wot package
    - Created unit tests for WotThing, WotValue, WotPrimitiveJsonType, and utility functions.
    - Implemented tests for property, action, and event management in WotThing.
    - Added tests for WotValue to ensure correct behavior with updates and notifications.
    - Included edge case handling and performance tests for concurrent access.
    - Updated pubspec.yaml to reflect the new package structure and dependencies.
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2025-07-25 feat: Add custom actions and properties for LED schedule, acclimation settings, location, and correction method in LyfiThing
2025-07-25 Refactor service interfaces and implementations
    - Replaced instances of IAppNotificationService with AppNotificationService.
    - Updated imports and usages of IGroupManager and ISceneManager to GroupManager and SceneManager respectively.
    - Introduced new abstract classes for DeviceManager, GroupManager, and SceneManager.
    - Refactored related implementations to align with the new structure.
    - Updated main application and view models to use the new service interfaces.
    - Adjusted tests to accommodate the changes in service interfaces.
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2025-07-26 refactor: Replace IDeviceManager with DeviceManager across the codebase for improved consistency and clarity
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2025-07-30 refactor: Wrap device re-binding and loading WotThings in an unawaited async function for improved readability
2025-07-30 feat: Update timeout durations for device discovery and binding to improve performance
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2025-07-31 fix: Trim whitespace in form validation and enhance device group handling in GroupedDevicesViewModel
2025-07-31 feat: Implement centralized device exception handling and integrate into device view models for improved error management
2025-07-31 feat: Add NetworkInterfaceHelper for inferring network interfaces and update device binding logic to utilize inferred addresses
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2025-08-01 fix: Update artifact paths in CI workflow and improve device discovery screen localization
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2025-08-03 refactor: Replace static logger with instance logger in DeviceExceptionHandler and simplify device status handling in view models
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2025-08-03 fix: Refactor group filtering logic and improve conditional rendering for 'No group' tile
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2025-08-09 Refactor error handling macros and update function calls for improved error reporting
    - Changed the window size for ADC from 9 to 7 in adc.h.
    - Added new NVS helper functions for getting values with default handling in nvs.h.
    - Enhanced error handling in try.h with new macros for ESP error types.
    - Updated event handler registrations in coap.c, mdns.c, power.c, rtc.c, system.c, wifi/blufi.c, and wifi/sc.c to use the new error handling macros.
    - Refactored NVS open functions in nvs.c to utilize error handling macros.
    - Improved button initialization and event posting in button.c.
    - Updated LED initialization and event handling in led.c.
    - Enhanced protection settings in protect.c with error h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
    [button.c, led.c]
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2025-08-13 fix: Update NTC temperature reading function to use unfiltered ADC reading and add delay in thermal initialization for stability
    [ntc.c]
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2025-09-09 Refactor routine management to chore management
    - Replaced RoutineManager with ChoreManager in app.dart.
    - Introduced ChoreHistoryStore to manage chore execution history.
    - Created ChoreManager to handle chore execution and undo functionality.
    - Removed RoutineHistoryStore and RoutineManager as they are no longer needed.
    - Added abstract chore model and built-in chore implementations.
    - Implemented chore actions for power and LED switch modes.
    - Developed view models for chore summary and chore list.
    - Updated UI components to display chore cards and lists.
    - Adjusted asset paths in pubspec.yaml for chore icons.
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2025-09-17 refactor(fan): fix initialization logging and ensure proper DAC voltage setting
    [fan.c]
2025-09-17 refactor(fan): correct DAC value logging in fan_set_power function
    [fan.c]
2025-09-18 Refactor LED settings management and update product configurations
    - Reorganized the LED settings management code in `settings.c` for improved readability and maintainability.
    - Updated product configuration files for `blc05emk1`, `blc05mk2`, `blc06mk1`, and `ulva6` to replace `CONFIG_LYFI_STANDALONE_CONTROLLER` with `CONFIG_BORNEO_PRODUCT_MODE_STANDALONE` or `CONFIG_BORNEO_PRODUCT_MODE_FULL` as appropriate.
    - Ensured consistent formatting and alignment of configuration parameters across product files.
    [settings.c]
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2025-09-18 fix(fan): ensure DAC and PWM initialization sets correct duty values
    [fan.c]
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2025-09-20 fix(indicator): update system event handler registration to use ESP_EVENT_ANY_ID
    [indicator_gpio.c]
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2025-09-25 Refactor fan and LED settings modules
    - Reorganized includes and improved code formatting in fan.c and settings.c.
    - Enhanced the initialization process for fan settings, ensuring proper loading of factory settings.
    - Improved error handling in LED settings loading and saving functions.
    - Added checks for geographical location validity in led_set_geo_location.
    - Updated comments for clarity and maintainability.
    [adc.c, fan.c, indicator_gpio.c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]
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2025-10-04 fix: Ensure PWM frequency is saved to NVS if not found and commit changes
    [settings.c]
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2025-10-06 fix: Update color for "N/A" text in dashboard tiles and include online status check for temperature display
2025-10-06 fix: Correct board names for BLC06MK1 and BST XIAOC3, enable fan control features
    [fan.c]
2025-10-06 fix: Mark led_set_duties as unused to avoid compiler warnings; update solar_calculate_local_tz_offset to use a copy of tm_local
    [led.c]
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2025-10-12 fix: Update memory block symbols in DAC and PWM initialization to 64
2025-10-13 fix: Update power measurement initialization logs for clarity and version bump to 0.3.30
2025-10-13 fix: Simplify ADC channel configuration and reading functions, and update calibration bitwidth
    [adc.c]
2025-10-13 fix: Update power supply voltage factor from 16242 to 15242 and bump version to 0.3.31
2025-10-14 fix: Replace 'ikernel' and 'idriver' imports with 'kernel' and 'driver' in multiple files
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2025-10-14 fix: Refactor driver data handling by removing cancellation token support and simplifying setDriverData method
2025-10-14 fix: Replace IDriver with Driver in multiple files to unify driver interface
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2025-10-14 fix: Simplify color update logic in editor view models and ensure device is not busy before setting color
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2025-10-15 refactor: Replace busy check with queue handling in device drivers and improve timezone conversion logic
2025-10-15 fix: Implement queue handling for device operations to improve concurrency and reliability
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2025-10-19 Refactor COAP resource handling and introduce RPC functions for LyFi core
    - Removed direct COAP handling code for color, schedule, info, status, temperature, state, correction method, mode, temporary duration, geo location, timezone enabled, and timezone offset.
    - Introduced new RPC functions in `lyfi-core.c` to handle the aforementioned operations, improving modularity and code organization.
    - Updated `lyfi-core.c` to utilize the new RPC functions, streamlining the COAP resource handling.
    - Added new RPC function declarations in `rpc.h` for better interface management.
    - Removed unused encoding functions related to channel information, as they are no longer necessary with the new RPC struct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
2025-11-07 refactor: Ensure isBusy state is reset and listeners notified after device setting updates
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2025-11-08 refactor: Replace hardcoded LED channel count with dynamic retrieval from factory settings
    [led.c, settings.c]
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2025-11-08 refactor: Remove DAC duty cycle configuration in fan control and replace with voltage regulator settings
    [fan.c]
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2025-11-08 fix: Correct type casting for rmtpwm_generator_t in _vreg_init function
    [vreg_rmtpwm.c]
2025-11-08 fix: Update rmtpwm_generator_t pointer casting in _vreg_init and _set_duty functions
    [vreg_rmtpwm.c]
2025-11-08 fix: Correct reference to vreg_driver_api in DRVFX_DEVICE_DEFINE macro
    [vreg_rmtpwm.c]
2025-11-08 fix: Include missing header for vreg.h in vreg_rmtpwm.c
    [vreg_rmtpwm.c]
2025-11-08 fix: Update DRVFX_DEVICE_DEFINE priority for vreg device initialization
    [vreg_rmtpwm.c]
2025-11-08 fix: Move dac_config initialization before data assignment in _vreg_init function
    [vreg_rmtpwm.c]
2025-11-08 fix: Improve error logging in k_device_is_ready function for NULL device and state
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2025-11-08 fix: Correct extern declarations for device start and end arrays fix: Update version to 0.3.39
2025-11-09 fix: Rename DAC channel configuration for clarity in voltage regulator
    [fan.c, vreg_rmtpwm.c]
2025-11-09 fix: Update fan control to use voltage regulator flags instead of DAC flags
    [fan.c]
2025-11-09 fix: Update voltage regulator output to use FAN_POWER_MAX constant
    [fan.c]
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2025-11-09 fix: Simplify fan initialization by removing unused VREG and PWM support code
    [fan.c]
2025-11-09 fix: Remove unused VREG and PWM support code from fan initialization
    [fan.c]
2025-11-09 fix: Initialize fan power to maximum on startup and update version to 0.3.46
    [fan.c]
2025-11-09 fix: Update indicator GPIO handling to use timer-based approach and increment version to 0.3.47
    [indicator_gpio.c]
2025-11-09 fix: Update LED state in indicator timer callback and increment version to 0.3.48
    [indicator_gpio.c]
2025-11-09 fix: Update LED manual color values and improve channel encoding logic
    [settings.c]
2025-11-09 fix: Update channel count checks in LED encoding logic to use strict comparison
2025-11-09 fix: Update channel count checks in LED encoding logic to use inclusive comparison
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2025-11-09 fix: Add mutex for thread safety in ADC read operations
    [adc.c]
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2026-01-11 Update localization files and improve device discovery functionality
    - Updated POT and PO files for English, Spanish, and Chinese translations with new strings and corrections.
    - Enhanced error handling in BLE provisioning and WiFi scanning services to rethrow exceptions instead of returning empty lists.
    - Integrated cancellation tokens in device discovery to manage ongoing scans more effectively.
    - Improved UI in device discovery screen to display error messages and loading indicators.
    - Added support for refreshing device discovery and handling no devices found scenario.
2026-01-17 fix: Correct SECS_PER_DAY definition and add critical section handling in LED functions
    [led.c]
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2026-01-17 fix: Correct time alignment logic in LED scheduler and update version to 0.4.2
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2026-01-18 fix: Optimize LED duty cycle calculation by using pre-allocated hpoint values, update version to 0.4.6
    [led.c]
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2026-01-26 fix(client/ios): Fix BLE provisioning and mDNS discovery on iOS
    Three issues were preventing the iOS app from discovering and
    provisioning Borneo devices:
    1. BLE Provisioning Security Mismatch
    The iOS ESP BLE provisioning plugin used `.secure` mode while the
    firmware uses `NETWORK_PROV_SECURITY_0` (unsecured). Changed to
    `.unsecure` to match.
    2. Missing NSBonjourServices Declaration
    iOS 14+ requires apps to declare Bonjour service types they want to
    browse. Added `_borneo._udp.` to Info.plist to enable mDNS discovery.
    3. Discovery UI Blocking on mDNS
    The device discovery screen used `Future.wait()` for both mDNS and
    BLE, but mDNS runs continuously until stopped. This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
2026-02-05 fix: Update UI components and improve device handling; bump version to 0.4.24-beta+0
    [led.c]
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2026-02-05 fix: Remove unnecessary led_fade_to_normal call in dimming state logic; bump version to 0.4.15
    [led.c]
2026-02-05 fix: Update DashboardPowerTile and DashboardTemporaryTile to conditionally render UI elements based on online status; adjust fan control GPIO in sdkconfig.board
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2026-02-05 fix: Refactor device deletion logic and update nullable handling in device scanning methods
2026-02-05 fix: Update device addition notification to use app notification service for better user feedback
2026-02-06 fix: Enhance device status updates by adding change detection and improve API calls in view models
2026-02-06 Update Chinese localization for various device settings and screens
    - Adjusted translation strings for device settings, including power behavior, fan mode, and thermal management.
    - Updated references in the localization file to reflect changes in the codebase.
    - Added new strings for device name validation and error messages.
    - Revised existing translations for clarity and consistency.
    - Ensured all relevant UI elements are properly localized for the Chinese language.
2026-02-07 fix: Refactor fan, power, and temperature tiles to improve digit rendering and leading zero handling
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2026-02-07 feat: Add Lyfi WOT actions, properties, and thing implementation
    - Implemented custom actions for switching modes, setting colors, schedules, acclimation settings, geographic location, and correction methods in `wot-actions.dart`.
    - Created properties for state, mode, power, schedule, acclimation settings, location, and correction method in `wot-properties.dart`, with event subscriptions for real-time updates.
    - Developed `LyfiThing` class in `wot-thing.dart` to manage device properties, initialize hardware bindings, and handle periodic synchronization and event subscriptions.
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2026-02-07 feat: Add new properties and API bindings for enhanced Lyfi device functionality
2026-02-07 feat: Refactor Lyfi device handling and improve WOT integration with enhanced error logging
2026-02-07 feat: Add voltage, current, and power properties to LyfiThing and update bindings in view models
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2026-02-08 feat: Improve WotThing handling and error management across device modules for enhanced reliability
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2026-02-12 refactor: Validate acclimation settings and enhance error handling
    [led.c, settings.c]
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2026-02-12 Update Chinese localization for various device settings and features
    - Adjusted translation strings for device settings, including fan modes, power behavior, and location services.
    - Updated timestamps for POT creation and revision dates.
    - Added new strings for acclimation and moon settings.
    - Corrected references in the localization files to match the updated code structure.
    - Improved clarity and consistency in translations across different screens and functionalities.
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2026-02-15 fix: Update dependencies and improve UI responsiveness in LyFi views
    [led.c, settings.c]
2026-02-15 fix: Update correction method to CIE1931 and bump version to 0.4.23
    [settings.c]
2026-02-15 fix: Adjust PID integral limits and add output slew rate control; bump version to 0.4.24
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2026-02-18 feat: Enhance error handling in DeviceCard by replacing GestureDetector with InkWell for improved user interaction
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2026-02-18 feat: Add networking and factory reset RPC methods for enhanced device management
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2026-02-20 feat: Enhance BLE permission handling in DeviceDiscoveryViewModel
    - Added a method to request BLE permissions and check their status before starting device discovery.
    - Updated _startBleScan to handle permission denial and provide appropriate error messages.
    - Introduced a requestBlePermissions callback for easier testing of permission scenarios.
    - Modified the device discovery screen to change the button text from "Cancel" to "Stop".
    - Added comprehensive unit tests for permission handling in DeviceDiscoveryViewModel.
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2026-02-20 feat: Introduce new kernel interfaces for device management including DiscoveryManager, BindingEngine, and HeartbeatService
2026-02-20 feat: Refactor kernel architecture by introducing BindingEngine and DiscoveryManager implementations
    - Added DefaultBindingEngine and DefaultDiscoveryManager classes to manage device binding and discovery.
    - Updated IKernel to support custom BindingEngine and DiscoveryManager injection.
    - Enhanced event handling for device binding and discovery events.
    - Modified .gitignore to include .design-docs.
    - Added tests for new BindingEngine and DiscoveryManager functionalities.
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2026-02-22 Refactor device group management tests and UI components
    - Moved device group management tests from `app_test.dart` to a new file `device_group_test.dart` for better organization and modularity.
    - Updated `app.dart` to accept an initial locale parameter for improved localization handling.
    - Refactored `GroupManagerImpl` to streamline group creation, updating, and deletion processes, ensuring events are fired after transactions complete.
    - Enhanced `GroupedDevicesViewModel` to prevent race conditions during device group updates.
    - Converted `GroupEditScreen` from a stateless to a stateful widget, implementing text controllers for better form handling and validation.
    - Replaced the delete conf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

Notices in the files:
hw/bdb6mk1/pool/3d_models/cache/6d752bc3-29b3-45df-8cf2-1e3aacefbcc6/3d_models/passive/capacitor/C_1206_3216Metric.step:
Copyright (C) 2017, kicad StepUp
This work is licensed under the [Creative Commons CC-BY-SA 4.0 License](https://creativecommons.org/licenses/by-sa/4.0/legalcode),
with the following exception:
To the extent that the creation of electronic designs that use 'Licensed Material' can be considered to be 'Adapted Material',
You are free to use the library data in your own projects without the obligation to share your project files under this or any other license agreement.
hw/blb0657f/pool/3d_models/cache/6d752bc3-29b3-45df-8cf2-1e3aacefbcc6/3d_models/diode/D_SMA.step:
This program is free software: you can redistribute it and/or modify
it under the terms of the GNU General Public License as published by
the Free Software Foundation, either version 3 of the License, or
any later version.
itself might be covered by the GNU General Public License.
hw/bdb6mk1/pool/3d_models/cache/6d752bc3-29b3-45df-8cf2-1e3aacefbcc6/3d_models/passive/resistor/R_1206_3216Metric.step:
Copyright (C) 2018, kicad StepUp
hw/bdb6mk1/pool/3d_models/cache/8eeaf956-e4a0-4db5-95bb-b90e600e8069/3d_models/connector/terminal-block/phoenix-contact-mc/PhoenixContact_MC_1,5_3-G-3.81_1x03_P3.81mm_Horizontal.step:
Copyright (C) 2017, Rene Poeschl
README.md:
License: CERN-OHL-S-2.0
